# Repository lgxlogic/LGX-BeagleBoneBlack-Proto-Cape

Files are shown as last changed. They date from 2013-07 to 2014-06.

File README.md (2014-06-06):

BeagleBone Black Proto Cape
===========================

This repository contains the Eagle design files for the LGX Proto Cape for the BeagleBone Black.  

Check out the LGX Proto Cape at http://www.logicsupply.com/products/cbb_proto  

**NOTE**: On CBB-Proto r01 the **SYS5V** and **VDD5V** labels are reversed. This is only
a concern if drawing higher currents from the 5V rail, or when supplying power 
to the BeagleBone through the proto cape instead of the DC barrel jack. In 
both cases the bus labelled **SYS5V** should be used, as it is connected directly 
to the BeagleBone's DC input.  

----

Follow us on Google+ for updates and more information: https://plus.google.com/u/0/b/103613886667848850929/

Created by Alexander Hiam for LGX / Logic Supply.

Creative Commons Attribution 3.0 Unported License.  
To view a copy of this license,visit http://creativecommons.org/licenses/by/3.0/.  
All text above must be included in any redistribution.

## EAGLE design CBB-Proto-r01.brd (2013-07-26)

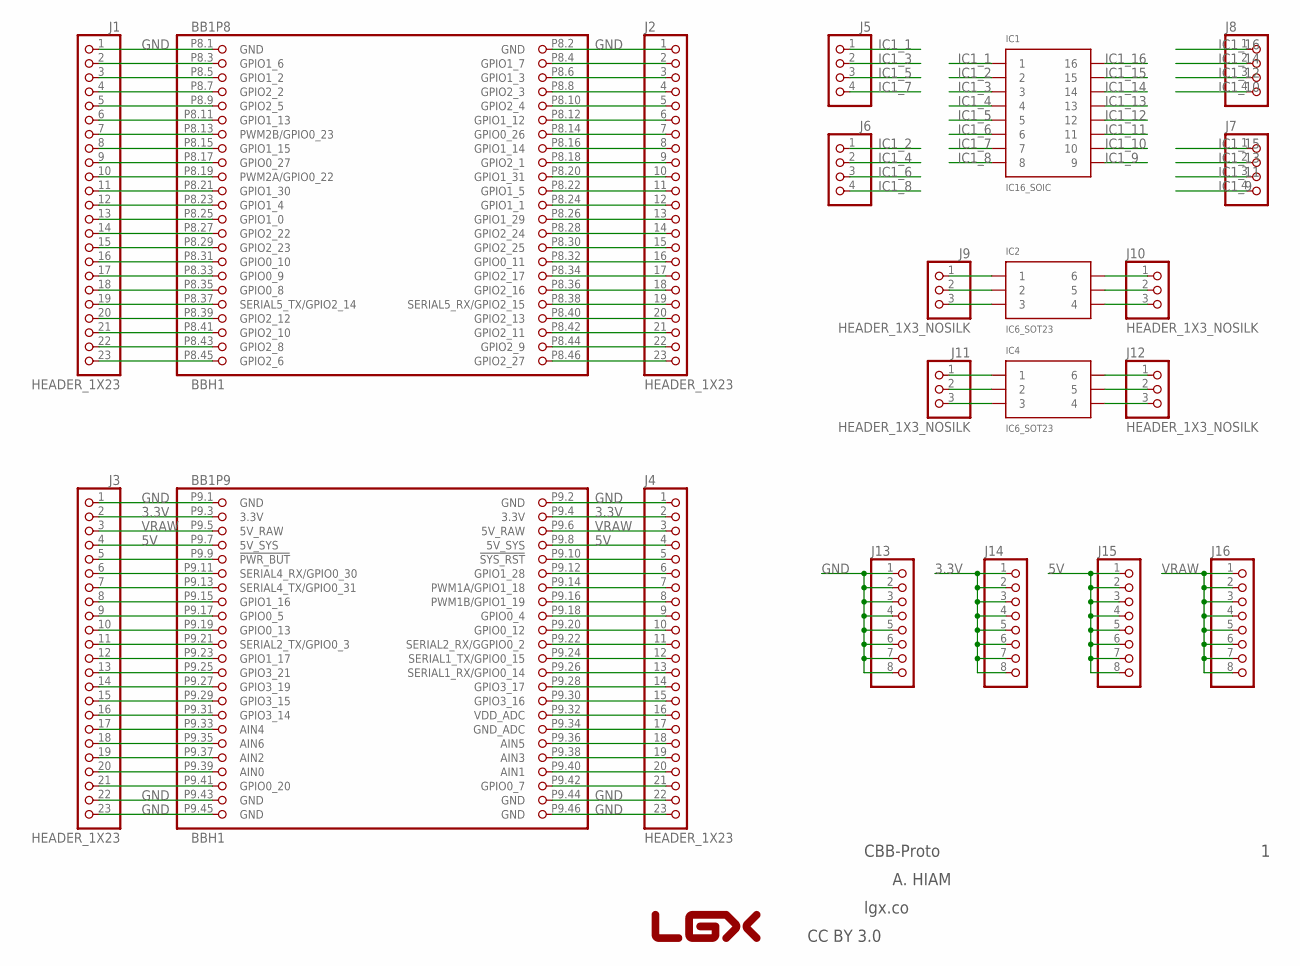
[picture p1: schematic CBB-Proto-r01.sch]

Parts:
BB1: BBH1; BB_CAPE
IC1: IC16_SOIC; SOIC16
IC2, IC4: IC6_SOT23; SOT23-6
J1, J2, J3, J4: HEADER_1X23
J5, J6, J7, J8: HEADER_1X4
J9, J10, J11, J12: HEADER_1X3_NOSILK
J13, J14, J15, J16: HEADER_1X8
U$1: LOGO-LGX

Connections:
3.3V: BB1.P9.3 (3.3V), BB1.P9.4 (3.3V), J3.2, J4.2, J14.1, J14.2, J14.3, J14.4, J14.5, J14.6, J14.7, J14.8
5V: BB1.P9.7 (5V_SYS), BB1.P9.8 (5V_SYS), J3.4, J4.4, J15.1, J15.2, J15.3, J15.4, J15.5, J15.6, J15.7, J15.8
GND: BB1.P8.1 (GND), BB1.P8.2 (GND), BB1.P9.1 (GND), BB1.P9.2 (GND), BB1.P9.43 (GND), BB1.P9.44 (GND), BB1.P9.45 (GND), BB1.P9.46 (GND), J1.1, J2.1, J3.1, J3.22, J3.23, J4.1, J4.22, J4.23, J13.1, J13.2, J13.3, J13.4, J13.5, J13.6, J13.7, J13.8
IC1_1: IC1.1, J5.1
IC1_2: IC1.2, J6.1
IC1_3: IC1.3, J5.2
IC1_4: IC1.4, J6.2
IC1_5: IC1.5, J5.3
IC1_6: IC1.6, J6.3
IC1_7: IC1.7, J5.4
IC1_8: IC1.8, J6.4
IC1_9: IC1.9, J7.4
IC1_10: IC1.10, J8.4
IC1_11: IC1.11, J7.3
IC1_12: IC1.12, J8.3
IC1_13: IC1.13, J7.2
IC1_14: IC1.14, J8.2
IC1_15: IC1.15, J7.1
IC1_16: IC1.16, J8.1
unnamed: BB1.P8.4 (GPIO1_7), J2.2
unnamed: BB1.P8.6 (GPIO1_3), J2.3
unnamed: BB1.P8.8 (GPIO2_3), J2.4
unnamed: BB1.P8.10 (GPIO2_4), J2.5
unnamed: BB1.P8.12 (GPIO1_12), J2.6
unnamed: BB1.P8.14 (GPIO0_26), J2.7
unnamed: BB1.P8.16 (GPIO1_14), J2.8
unnamed: BB1.P8.18 (GPIO2_1), J2.9
unnamed: BB1.P8.20 (GPIO1_31), J2.10
unnamed: BB1.P8.22 (GPIO1_5), J2.11
unnamed: BB1.P8.24 (GPIO1_1), J2.12
unnamed: BB1.P8.26 (GPIO1_29), J2.13
unnamed: BB1.P8.28 (GPIO2_24), J2.14
unnamed: BB1.P8.30 (GPIO2_25), J2.15
unnamed: BB1.P8.32 (GPIO0_11), J2.16
unnamed: BB1.P8.34 (GPIO2_17), J2.17
unnamed: BB1.P8.36 (GPIO2_16), J2.18
unnamed: BB1.P8.38 (SERIAL5_RX/GPIO2_15), J2.19
unnamed: BB1.P8.40 (GPIO2_13), J2.20
unnamed: BB1.P8.42 (GPIO2_11), J2.21
unnamed: BB1.P8.44 (GPIO2_9), J2.22
unnamed: BB1.P8.46 (GPIO2_27), J2.23
unnamed: BB1.P8.45 (GPIO2_6), J1.23
unnamed: BB1.P8.43 (GPIO2_8), J1.22
unnamed: BB1.P8.41 (GPIO2_10), J1.21
unnamed: BB1.P8.39 (GPIO2_12), J1.20
unnamed: BB1.P8.37 (SERIAL5_TX/GPIO2_14), J1.19
unnamed: BB1.P8.35 (GPIO0_8), J1.18
unnamed: BB1.P8.33 (GPIO0_9), J1.17
unnamed: BB1.P8.31 (GPIO0_10), J1.16
unnamed: BB1.P8.29 (GPIO2_23), J1.15
unnamed: BB1.P8.27 (GPIO2_22), J1.14
unnamed: BB1.P8.25 (GPIO1_0), J1.13
unnamed: BB1.P8.23 (GPIO1_4), J1.12
unnamed: BB1.P8.21 (GPIO1_30), J1.11
unnamed: BB1.P8.19 (PWM2A/GPIO0_22), J1.10
unnamed: BB1.P8.17 (GPIO0_27), J1.9
unnamed: BB1.P8.15 (GPIO1_15), J1.8
unnamed: BB1.P8.13 (PWM2B/GPIO0_23), J1.7
unnamed: BB1.P8.11 (GPIO1_13), J1.6
unnamed: BB1.P8.9 (GPIO2_5), J1.5
unnamed: BB1.P8.7 (GPIO2_2), J1.4
unnamed: BB1.P8.5 (GPIO1_2), J1.3
unnamed: BB1.P8.3 (GPIO1_6), J1.2
unnamed: BB1.P9.41 (GPIO0_20), J3.21
unnamed: BB1.P9.39 (AIN0), J3.20
unnamed: BB1.P9.37 (AIN2), J3.19
unnamed: BB1.P9.35 (AIN6), J3.18
unnamed: BB1.P9.33 (AIN4), J3.17
unnamed: BB1.P9.31 (GPIO3_14), J3.16
unnamed: BB1.P9.29 (GPIO3_15), J3.15
unnamed: BB1.P9.27 (GPIO3_19), J3.14
unnamed: BB1.P9.25 (GPIO3_21), J3.13
unnamed: BB1.P9.23 (GPIO1_17), J3.12
unnamed: BB1.P9.21 (SERIAL2_TX/GPIO0_3), J3.11
unnamed: BB1.P9.19 (GPIO0_13), J3.10
unnamed: BB1.P9.17 (GPIO0_5), J3.9
unnamed: BB1.P9.15 (GPIO1_16), J3.8
unnamed: BB1.P9.13 (SERIAL4_TX/GPIO0_31), J3.7
unnamed: BB1.P9.11 (SERIAL4_RX/GPIO0_30), J3.6
unnamed: BB1.P9.9 (!PWR_BUT), J3.5
unnamed: BB1.P9.10 (!SYS_RST), J4.5
unnamed: BB1.P9.12 (GPIO1_28), J4.6
unnamed: BB1.P9.14 (PWM1A/GPIO1_18), J4.7
unnamed: BB1.P9.16 (PWM1B/GPIO1_19), J4.8
unnamed: BB1.P9.18 (GPIO0_4), J4.9
unnamed: BB1.P9.20 (GPIO0_12), J4.10
unnamed: BB1.P9.22 (SERIAL2_RX/GGPIO0_2), J4.11
unnamed: BB1.P9.24 (SERIAL1_TX/GPIO0_15), J4.12
unnamed: BB1.P9.26 (SERIAL1_RX/GPIO0_14), J4.13
unnamed: BB1.P9.28 (GPIO3_17), J4.14
unnamed: BB1.P9.30 (GPIO3_16), J4.15
unnamed: BB1.P9.32 (VDD_ADC), J4.16
unnamed: BB1.P9.34 (GND_ADC), J4.17
unnamed: BB1.P9.36 (AIN5), J4.18
unnamed: BB1.P9.38 (AIN3), J4.19
unnamed: BB1.P9.40 (AIN1), J4.20
unnamed: BB1.P9.42 (GPIO0_7), J4.21
unnamed: IC2.1, J9.1
unnamed: IC2.2, J9.2
unnamed: IC2.3, J9.3
unnamed: IC2.6, J10.1
unnamed: IC2.5, J10.2
unnamed: IC2.4, J10.3
unnamed: IC4.1, J11.1
unnamed: IC4.2, J11.2
unnamed: IC4.3, J11.3
unnamed: IC4.6, J12.1
unnamed: IC4.5, J12.2
unnamed: IC4.4, J12.3
VRAW: BB1.P9.5 (5V_RAW), BB1.P9.6 (5V_RAW), J3.3, J4.3, J16.1, J16.2, J16.3, J16.4, J16.5, J16.6, J16.7, J16.8

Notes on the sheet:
A. HIAM
CBB-Proto
lgx.co
CC BY 3.0

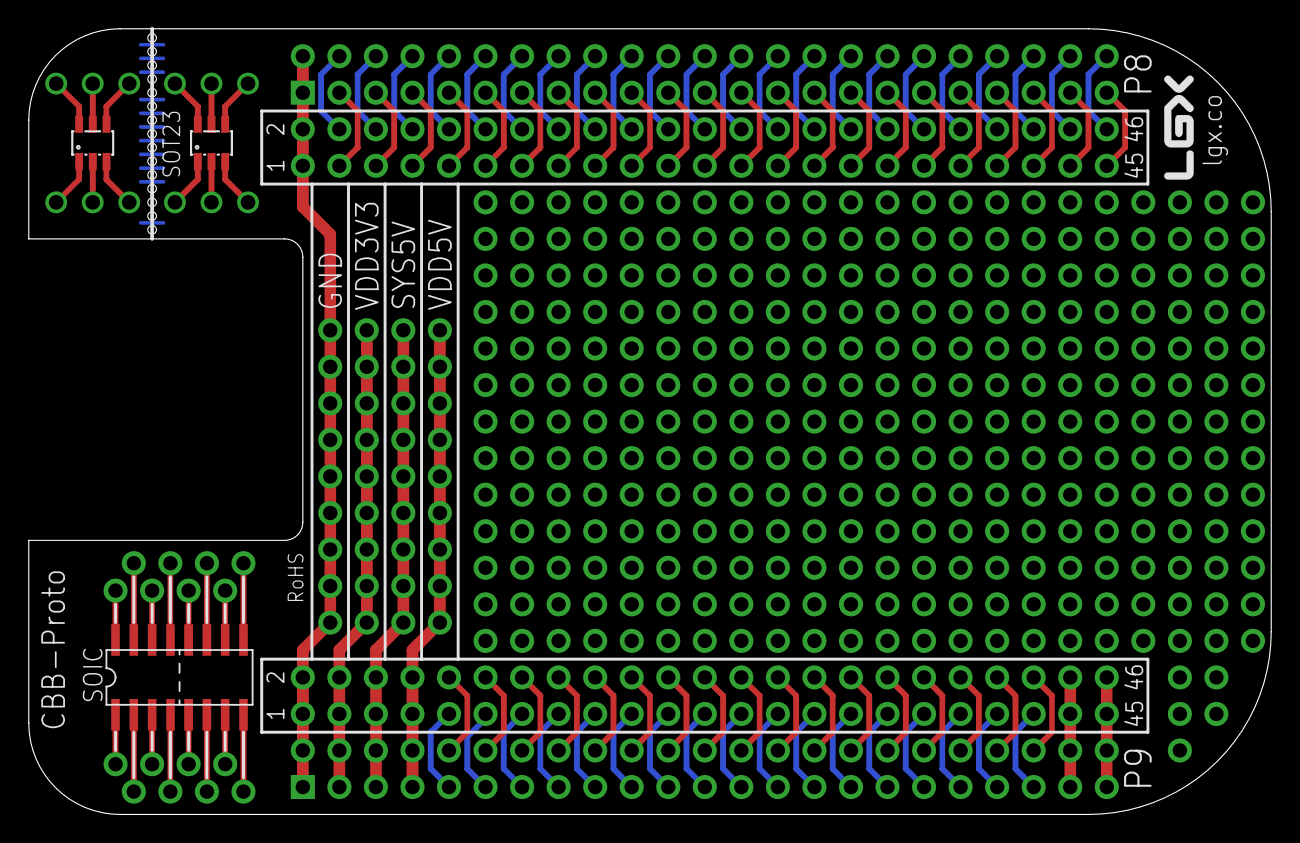
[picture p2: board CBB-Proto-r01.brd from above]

Board: 2 copper layers, 86.4 x 54.6 mm, 21 parts (0 on the bottom side), 110 nets.

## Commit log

2013-07-09 added Eagle design files
    [CBB-Proto-r02.brd, CBB-Proto-r02.sch]
2013-07-26 revert to r01
    [CBB-Proto-r01.brd, CBB-Proto-r01.sch, CBB-Proto-r02.sch]
2013-08-28 added schematic and layout PDFs
